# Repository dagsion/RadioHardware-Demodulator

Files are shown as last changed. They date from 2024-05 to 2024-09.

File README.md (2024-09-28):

# Radio-Demodulator
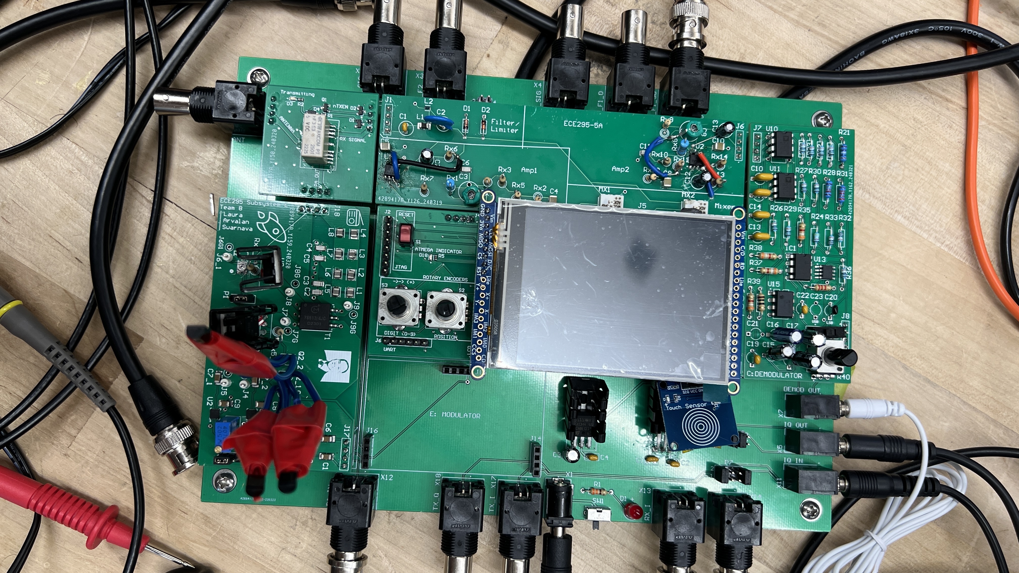
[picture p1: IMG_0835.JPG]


## Introduction
This project entails the collaborative effort of second-year ECE students, tasked with designing subsystems for a Software-Defined Radio (SDR) transceiver. My team, David Xu and Jinyu Xiao, focused on developing the demodulator and audio amplifier, serving as the final link in the receiver chain. This subsystem's core function involves converting processed radio signals into audio and subsequently amplifying it to drive large speakers.

## Design - Single Sideband Demodulator
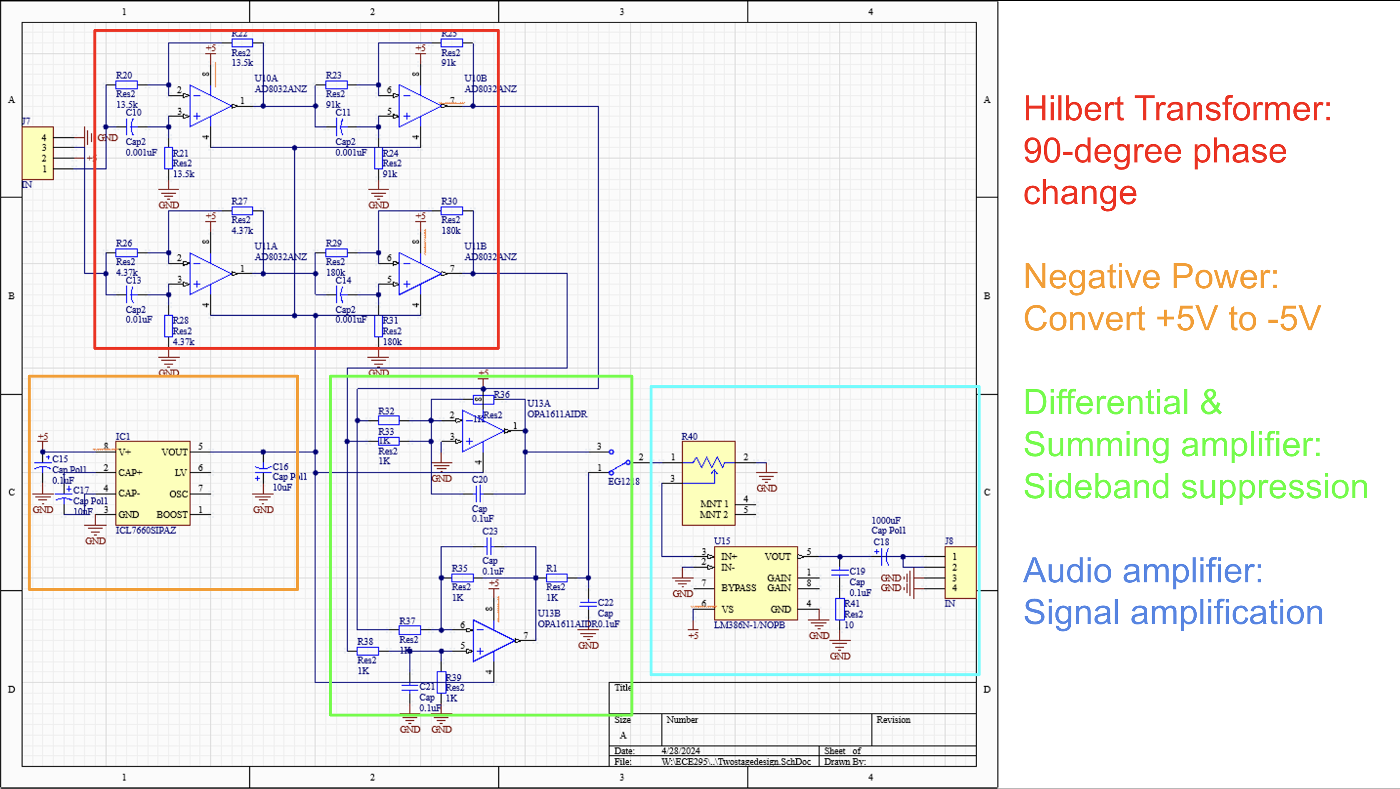
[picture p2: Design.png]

This is the design of the SSB demodulator on Altium. It is composed of four stages:
1. Hilbert Transformer creates a 90-degree phase change between the I/Q signal to enable Single-Sideband suppression. It is composed of two-stage all-pass-filters across frequency 100-3200Hz
2. Summing/differential Amplifier is responsible for Single-Sideband suppression.
3. A Negative Power Supply is required for most of the IC chips on the PCB
4. Audio Amplifier which is responsible for producing an audible output from the audio Jack
## Prototype
This is the Altium PCB Design. It is a single-layer double-sided PCB design. The Summing amplifier and the differential amplifier are selected through a switch. The switch also functions as a switch for USB and LSB demodulation. Moreover, the audio amplifier is controlled by a logarithm potentiometer.

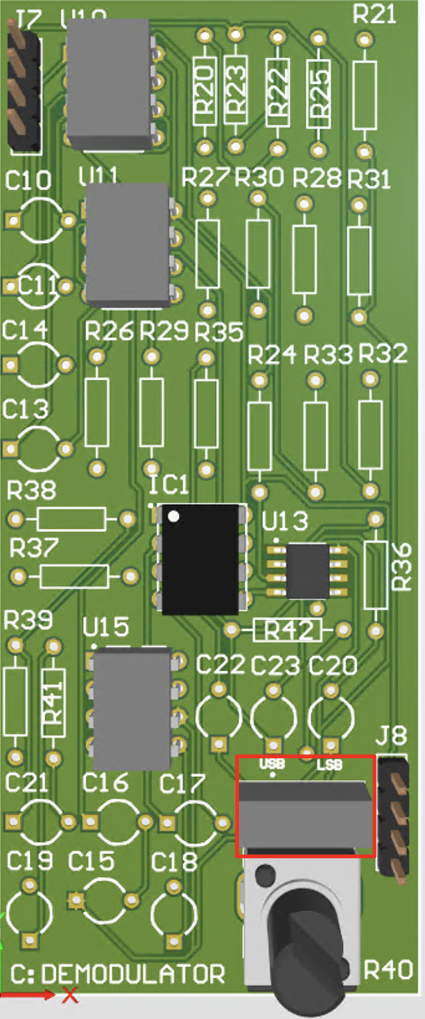
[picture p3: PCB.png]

## Assembly
This is the fully soldered PCB board. These two components left unsoldered which is the design decision we made for the final Low Pass Filter Design. We decide to use a passive Low Pass Filter for simplicity.
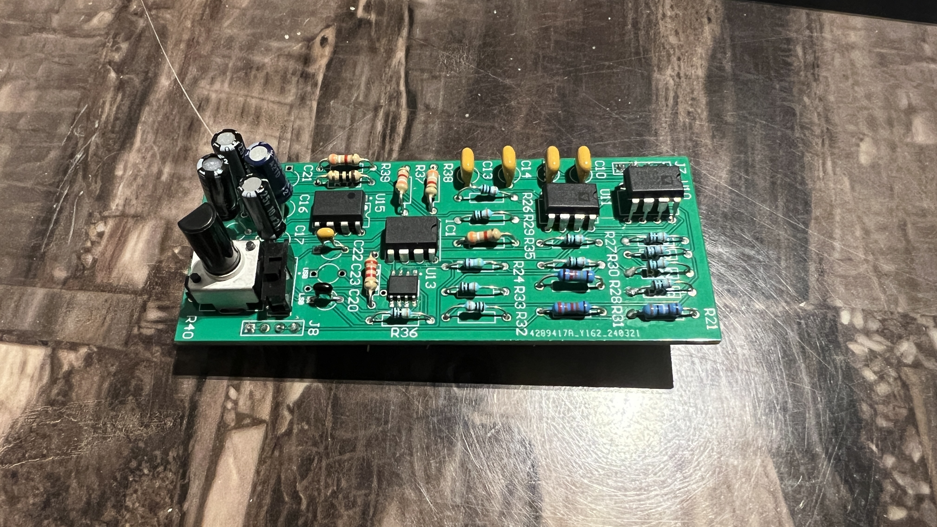
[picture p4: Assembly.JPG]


## Results
Check out this video

https://github.com/dagsion/RadioHardware-Demodulator/assets/117557771/a40ce58c-7ff9-4731-ac77-a94a2d153782

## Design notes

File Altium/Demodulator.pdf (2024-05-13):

Comment | Description | Designator | Footprint | LibRef | Quantity
EG1218 | Slide Switch, 500 V, -20 to 70 degC, 3-Pin THD, RoHS | | ESWI-EG1218_V | CMP-1696-00002-1 | 1
Cap2 | Capacitor | C10, C11, C13, C14 | CAPR5-4X5 | Cap2 | 4
Cap Pol1 | Polarized Capacitor (Radial) | C15, C16, C17, C18 | CAPR5-4X5 | Cap Pol1 | 4
Cap | Capacitor | C19, C20, C21, C22, C23 | CAPR5-4X5 | Cap | 5
ICL7660SIPAZ | ICL7660SIPAZ Charge Pump INV/STPUP/ STPDN -1.5V to -12V/ 1.5V to 22.8V 45mA 8-Pin PDIP Tube | IC1 | DIP762W45P254L960H5 33Q8B | CMP-00572-88254228-1 | 1
IN | Header, 4-Pin | J7, J8 | 61300411121 | MHDR1X4 | 2
Res2 | Resistor | R20, R21, R22, R23, R24, R25, R26, R27, R28, R29, R30, R31, R32, R33, R35, R36, R37, R38, R39, R41, R? | AXIAL-0.4 | Res2 | 21
PTV09A-4020F-A203 | POT 20K OHM 1/20W CARBON LOG | R40 | FP-PTV09A-4020-MFG | CMP-07234-000017-1 | 1
AD8032ANZ | Double Channel RRIO Operational Amplifier, 80 MHz BW, 35 V/us SR, Industrial, 8-pin DIP (N-8), Tube | U10, U11 | ADI-N-8 | CMP-0384-00245-2 | 2
OPA1611AIDR | 1.1 nV/rtHz Noise, Low Power, Precision Operational Amplifier, 4.5 to 36 V, -40 to 85 degC, 8-pin SOIC (D8), Green (RoHS & no Sb/ Br) | U13 | D0008A_M | CMP-0808-00013-2 | 1
LM386N-1/NOPB | Low Voltage Audio Power Amplifier, 8-pin MDIP, Pb-Free | U15 | P0008A | CMP-0057-00052-4 | 1

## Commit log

2024-05-12 Rename IMG_0761 (1).JPG to Assemble.JPG
2024-05-14 Create PCB
2024-05-14 Update and rename Demodulator.PrjPcb to Altium/Demodulator.PrjPcb
    [Demodulator.PrjPcb]
